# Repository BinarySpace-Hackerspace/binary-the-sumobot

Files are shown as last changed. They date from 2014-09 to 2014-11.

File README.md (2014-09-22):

Binary the SumoBot
==================

All related files for Binary the SumoBot

<b>Software</b>:

Various code available from some of the BinarySpace members

Sonar:

Library: http://playground.arduino.cc/Code/NewPing

<b>Hardware</b>:

If you just want to build one then want the following files:

sumo_v2.dxf - lasercut files
dozer_v2.stl - 3d printed bumper

If you want to modify then look at 

sumo.scad (openscad source)

Snippets used from the following scripts:

http://www.thingiverse.com/thing:9347
http://www.thingiverse.com/thing:18139

This was designed and built at BinarySpace (www.binaryspace.co.za)

Check out project page at http://www.binaryspace.co.za/?page_id=289

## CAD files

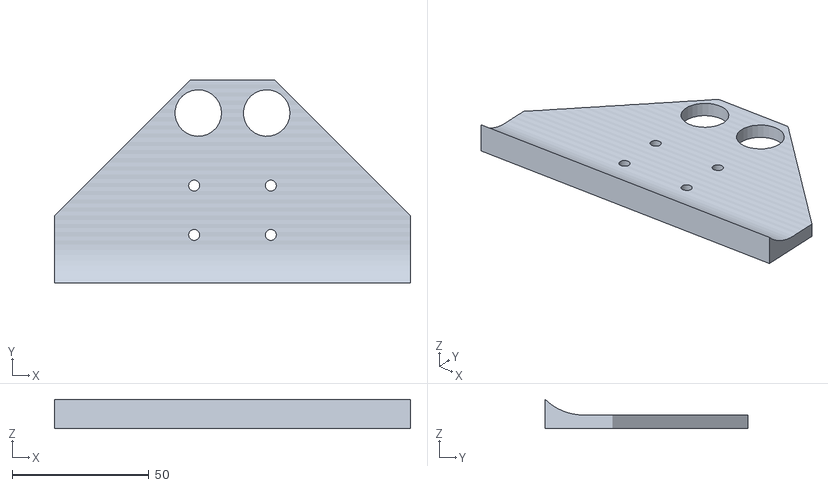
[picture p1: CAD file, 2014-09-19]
hardware/dozer_v2.stl
130.0 x 74.0 x 10.7

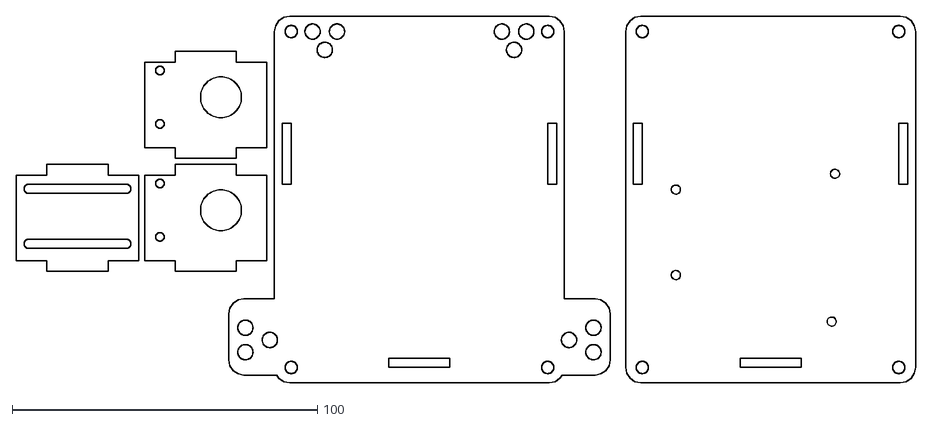
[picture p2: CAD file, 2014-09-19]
hardware/sumo_v2.dxf
294.5 x 120.0

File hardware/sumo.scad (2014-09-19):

// from http://www.thingiverse.com/thing:18139
include<arduino.scad>



projection( cut = true )
{


// dozerMount
translate( [-42, 0, 0] ) dozerMount();
// motorMount
translate( [0, 0, 0] ) motorMount();
translate( [0, 37, 0] ) motorMount();
// bottom base
translate( [90, 0, 0] ) bottomBase();

// top base - export as dxf for lasercut
translate( [205, 0, 0] ) topBase();
}



/*
// dozer - export as stl for 3d printing
dozerComplete();
*/

module dozerComplete()
{
	sonarHoleSize = 17;
	difference()
	{
		dozer();
		translate( [-67, 35, -20] ) rotate( [0, 0, -45] ) cube( [60, 120, 60] , center = true);
		translate( [67, 35, -20] ) rotate( [0, 0, 45] ) cube( [60, 120, 60], center = true );

		translate( [-12.5, 32, -10] )
		{
			cylinder( r = sonarHoleSize/2, h = 10 );
			translate( [25, 0, 0] ) cylinder( r = sonarHoleSize/2, h = 10 );
		}
		translate( [-25, 44, -20] ) cube( [50, 10, 40] );
	}
}

module dozer()
{


	rotate( [ 270, 0, 0] )
	{
		difference()
		{
			translate( [0, 0, 10] )cube( [ 130, 22, 80], center = true );
			translate( [0, 12, 0] ) cube( [ 130, 10, 120], center = true );


			for ( i = [0 : 20] )
			translate( [ -2, -18, -16 + (3 * i )] ) 
			{
				rotate( [ 0, 90, 0] ) cylinder( r = 20, h = 136, center = true, $fn = 64 );
			}

			translate( [-20, 15, -12] )
			{
				rotate( [0, 0, 90] )
				{
					translate( [0, 0, 23] ) 
					rotate( [90, 180, 90] )
					{

						translate( [0, 3, -30] )
						{
							translate( [6, 2.5, -2] ) cylinder( r = 2, h = 50, $fn = 64 );
							translate( [6, 2.5 + 18, -2] ) cylinder( r = 2, h = 50, $fn = 64 );
							translate( [34, 2.5, -2] ) cylinder( r = 2, h = 50, $fn = 64 );
							translate( [34, 2.5 + 18, -2] ) cylinder( r = 2, h = 50, $fn = 64 );
						}
					}
				}
			}
		}

	}
}


// from http://www.thingiverse.com/thing:9347
module roundedRect(size, radius)
{
	x = size[0];
	y = size[1];
	z = size[2];

	linear_extrude(height=z)
	
	hull()
	{
		// place 4 circles in the corners, with the given radius
		translate([(-x/2)+(radius/2), (-y/2)+(radius/2), 0])
		circle(r=radius);

		translate([(x/2)-(radius/2), (-y/2)+(radius/2), 0])
		circle(r=radius);

		translate([(-x/2)+(radius/2), (y/2)-(radius/2), 0])
		circle(r=radius);

		translate([(x/2)-(radius/2), (y/2)-(radius/2), 0])
		circle(r=radius);
	}
}


module bottomBase()
{
	difference()
	{
	union()
	{
		translate( [0, 15,0]) roundedRect( [90, 115, 3], 5 );

		// line follow sensors
		translate( [0, -30,0]) roundedRect( [120, 20, 3], 5 );
	}

	// spacer holes
	translate( [ 42, 70, -4] ) spacer();
	translate( [ -42, 70, -4] ) spacer();
	translate( [ 42, -40, -4] ) spacer();
	translate( [ -42, -40, -4] ) spacer();

	mounts();

	//line follow sensors mount
	translate( [-57, -27, -4] ) 
	{
		cylinder( r = 2.5, h = 10, $fn = 64 );
		translate( [0, -8, 0] ) cylinder( r = 2.5, h = 10, $fn = 64 );
		translate( [8, -4, 0] ) cylinder( r = 2.5, h = 10, $fn = 64 );
	}

	translate( [57, -27, -4] ) 
	{
		cylinder( r = 2.5, h = 10, $fn = 64 );
		translate( [0, -8, 0] ) cylinder( r = 2.5, h = 10, $fn = 64 );
		translate( [-8, -4, 0] ) cylinder( r = 2.5, h = 10, $fn = 64 );
	}

	translate( [35, 70, -4] ) 
	{
		cylinder( r = 2.5, h = 10, $fn = 64 );
		translate( [-8, 0, 0] ) cylinder( r = 2.5, h = 10, $fn = 64 );
		translate( [-4, -6, 0] ) cylinder( r = 2.5, h = 10, $fn = 64 );
	}

	translate( [-27, 70, -4] ) 
	{
		cylinder( r = 2.5, h = 10, $fn = 64 );
		translate( [-8, 0, 0] ) cylinder( r = 2.5, h = 10, $fn = 64 );
		translate( [-4, -6, 0] ) cylinder( r = 2.5, h = 10, $fn = 64 );
	}

	}
}


module topBase()
{
	difference()
	{
		translate( [0, 15,0]) roundedRect( [90, 115, 3], 5 );

		// spacer holes
		translate( [ 42, 70, -4] ) spacer();
		translate( [ -42, 70, -4] ) spacer();
		translate( [ 42, -40, -4] ) spacer();
		translate( [ -42, -40, -4] ) spacer();

		mounts();

//		translate( [-40, 34, 0] ) cube( [80, 30, 50] );
		translate([20,-25, 8]) rotate( [0, 0, 180] ) Arduino(1, 1, 1);

	}
}

module mounts()
{
	translate( [-45, 50, 3.1] ) 
	{
		translate( [0, 0, 23] ) 
		rotate( [90, 180, 90] )
		motorMount();
	}

	translate( [42, 50, 3.1] )
	{ 
		translate( [0, 0, 23] ) 
		rotate( [90, 180, 90] )
		motorMount();
	}

	translate( [-20, -40, 3.1] )
	{
		rotate( [0, 0, 90] ) 
		{
			translate( [0, 0, 23] ) 
			rotate( [90, 180, 90] )
			dozerMount();
		}
	}
}

module spacer()
{
	cylinder( r = 2, h = 25, $fn = 64 );
}

module dozerMount()
{
	difference()
	{
		union()
		{
			translate( [0, -5, 0] ) cube( [ 40, 28, 3] );
			translate( [ 10, -8.5, 0]) cube( [ 20, 35, 3] );
		}

		translate( [0, -2, 0] )
		{
			translate( [4, 2.5, -2] ) cylinder( r = 1.5, h = 10, $fn = 64 );
			translate( [4, 2.5 + 18, -2] ) cylinder( r = 1.5, h = 10, $fn = 64 );
			translate( [36, 2.5, -2] ) cylinder( r = 1.5, h = 10, $fn = 64 );
			translate( [36, 2.5 + 18, -2] ) cylinder( r = 1.5, h = 10, $fn = 64 );
		}

		translate( [4, -1, -3] ) cube( [32, 3, 10] );
		translate( [4, 17, -3] ) cube( [32, 3, 10] );

	}
}

module motorMount()
{
	difference()
	{
		union()
		{
			translate( [0, -5, 0] ) cube( [ 40, 28, 3] );
			translate( [ 10, -8.5, 0]) cube( [ 20, 35, 3] );
		}

		translate( [5, 2.75, -2] ) cylinder( r = 1.4, h = 10, $fn = 64 );
		translate( [5, 2.25 + 18, -2] ) cylinder( r = 1.4, h = 10, $fn = 64 );
		translate( [ 25, 11.5, -3] ) cylinder( r = 6.7, h = 10, $fn = 64 );
	}
}

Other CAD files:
hardware/arduino.scad

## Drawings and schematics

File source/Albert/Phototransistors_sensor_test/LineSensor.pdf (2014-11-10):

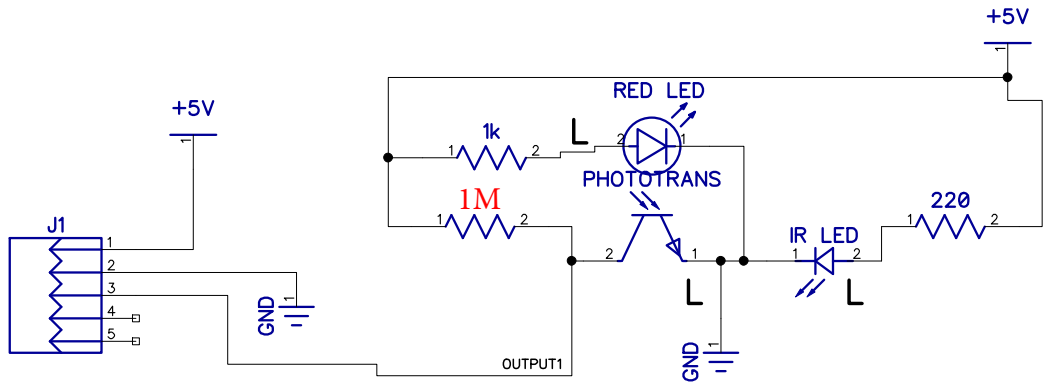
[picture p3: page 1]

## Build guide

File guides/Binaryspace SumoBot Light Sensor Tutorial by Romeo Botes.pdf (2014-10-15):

# Binaryspace SumoBot Light Sensor Tutorial

### By Romeo Botes (romeo.botes@gmail.com)

This tutorial shows how to build a simple IR Light Sensor for your SumoBot. You will need to build 4 sensors like these, two exactly the same and two others with a different pin layout for the other side of the SumoBot.

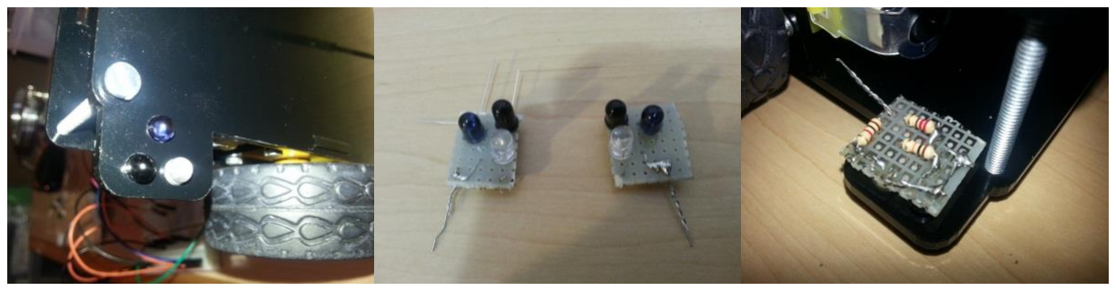
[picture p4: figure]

### Content:

1. Components
2. Placing
3. Soldering and Connecting
4. Cutting and Cleaning
5. Hook-up Wiring
6. Programming
7. Testing

### Components

- 1x 7pin by 5 pin cut Vero board (VB)
- 1x IR Transmitter (Tx)
- 1x IR Receiver (Rx)
- 1x LED (Any colour)
- 1x 10k Resistor
- 1x 1K Resistor
- 1x 220 Resistors
- 3x 0.2mm wire (red, black and any colour for signal in this example we used Yellow for signal)

PIN 1

PIN 7

PIN 8

### Placing

Place the components in the following matter on the VB (see Images).

- IR Tx
- Long Leg > Pin 7
- Short Leg > Pin 6
- IR Rx
- Long Leg > Pin 26
- Short Leg > Pin 27
- LED
- Long Leg > Pin 3
- Short Leg > Pin 4
- 1K Resistor
- Pin 1, 22
- 10K Resistor
- Pin 17, 20
- 220 Resistor
- Pin 30 ,33

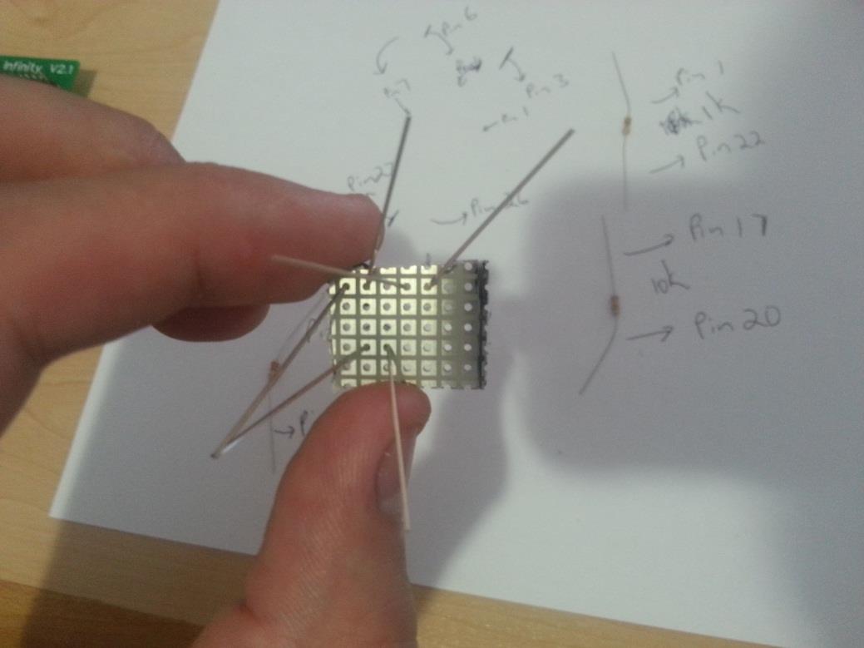
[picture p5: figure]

### Soldering and Connecting

Connect and solder the components in the following matter on the VB (see Images).

- Solder together Pin 4, 7, 27 this will be GND.
- Solder together Pin 17, 22, 30 this will be V5+.
- Connect and solder:
- Pin 1 to Pin 3
- Pin 6 to Pin 20
- Pin 26 to Pin 33

You can pull on of the Pins 17, 22, 30 through Pin-hole 29 and solder the other two at the back.

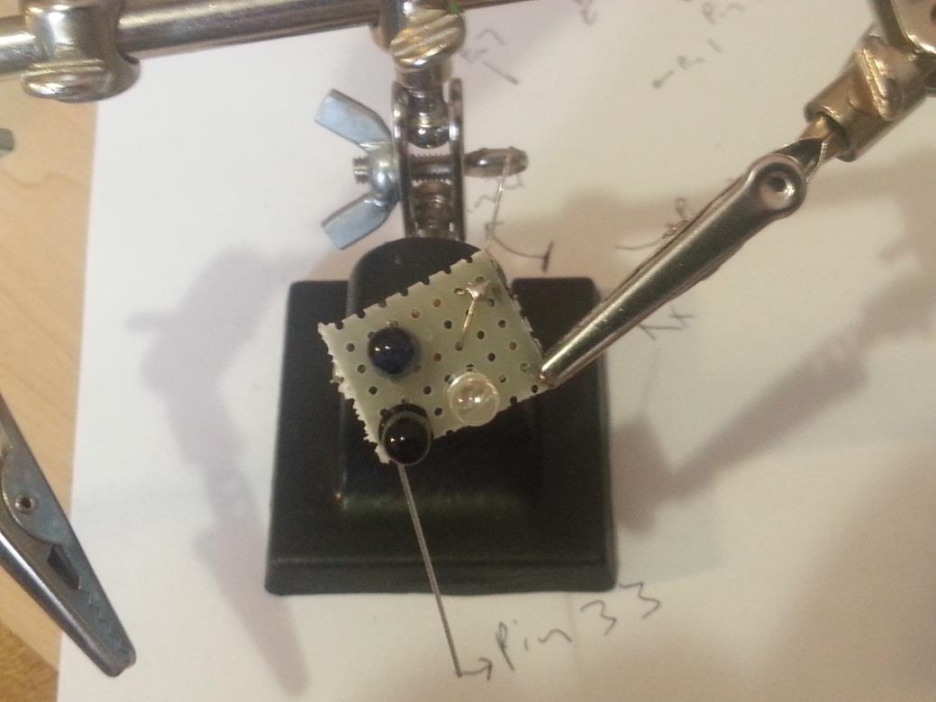
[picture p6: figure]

### Cutting and Cleaning

Cut away all excess wire leaving:

- The pulled thru wire on pin 29.
- One of the Pin 4, 7, 27 wires.

### Hook-up Wiring

Use your three 0.2mm wire (Red, Black, and Yellow) and connect them as follows:

- Connect Red wire to wire on Pin 29 and connect it to Arduino V5+.
- Connect Black wire to one of the Pin 4, 7, 27 wires and connect it to GND.
- Connect Yellow wire on the wire running between Pin 6 and Pin 20 and connect it to Arduino A0 or whichever one (A1-A5) you want to use for the sensor.

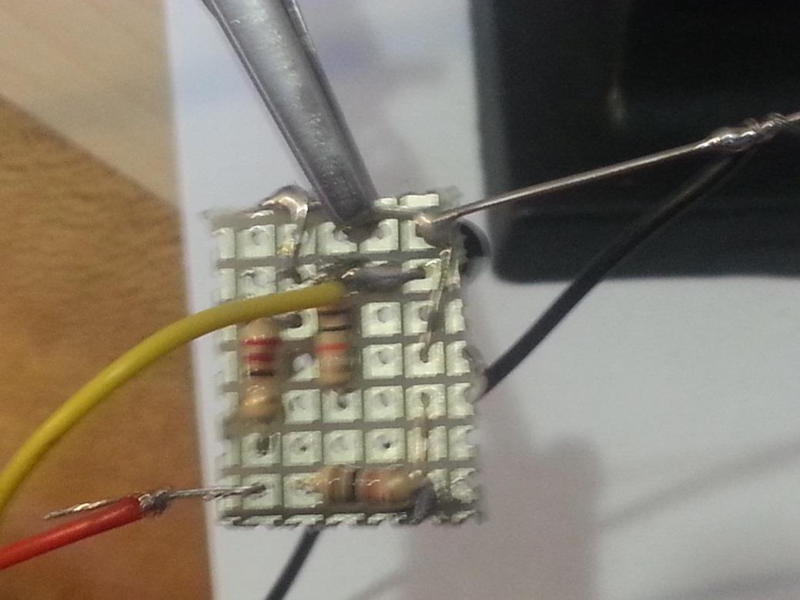
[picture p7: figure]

### Programming

Use the following code to test the sensor:

//////////////////////////////////////////////////////////////////////
int sensorPin = A0; // select the input pin for the potentiometer
int sensorValue = 0; // variable to store the value coming from the sensor

void setup() {
Serial.begin(9600);
}
void loop() {
// read the value from the sensor: sensorValue = analogRead(sensorPin); Serial.println(sensorValue);
delay(10);
}
//////////////////////////////////////////////////////////////////////

### Testing

When testing the sensor use a black and white piece of plastic, paper, etc.

DEFUALT AND BLACK MATTER

By default (point to nothing) and BLACK surfaces will present you with a high analogue value for the sensor of above 900, in our case it was about 995-996.

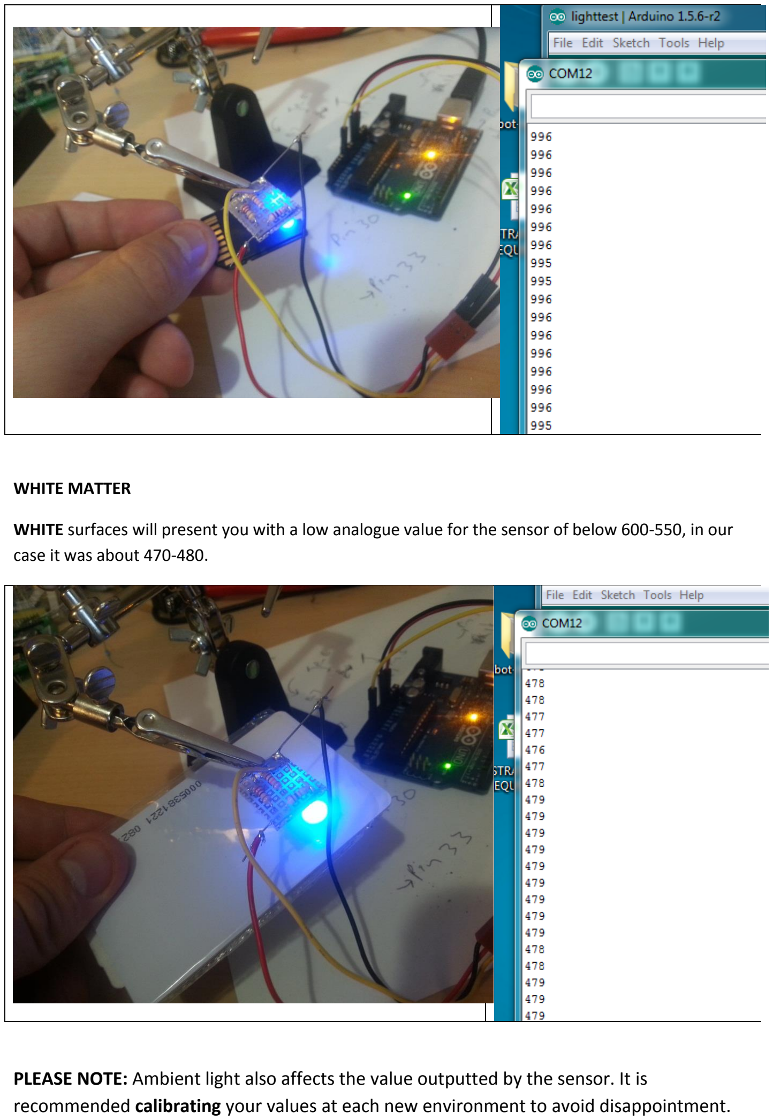
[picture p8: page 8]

WHITE MATTER

WHITE surfaces will present you with a low analogue value for the sensor of below 600-550, in our case it was about 470-480.

PLEASE NOTE: Ambient light also affects the value outputted by the sensor. It is recommended calibrating your values at each new environment to avoid disappointment.

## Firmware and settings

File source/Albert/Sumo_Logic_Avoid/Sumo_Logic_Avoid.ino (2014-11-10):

#define echoPin 4 // Echo Pin Input
#define trigPin 5 // Trigger Pin Output

#define motor1pole1 2 
#define motor1pole2 3
#define motor2pole1 7
#define motor2pole2 8

// map L293d motor enable pins to Arduino pins
#define enablePin1 9
#define enablePin2 10

#define M1_MAX_SPEED 100
#define M2_MAX_SPEED 100

#define motordelay 30
#define debugmotorsec 100

int mspeed = 160;  // pick a starting speed up to 255
int previousDistance;
int i;
int j;

void setup() {
  Serial.begin (115200);
  pinMode(trigPin, OUTPUT);
  pinMode(echoPin, INPUT);
  
  // set mapped L293D motor1 and motor 2 enable pins on Arduino to output (to turn on/off motor1 and motor2 via L293D)
  pinMode(enablePin1, OUTPUT);
  pinMode(enablePin2, OUTPUT);

  // set mapped motor poles to Arduino pins (via L293D)
  pinMode( motor1pole1 , OUTPUT);
  pinMode( motor1pole2, OUTPUT);
  pinMode( motor2pole1, OUTPUT);
  pinMode( motor2pole2 , OUTPUT);
  motorspeed(0, 0);
}

void loop() 
{
  echo();
  motorspeed(mspeed, mspeed);
}

void echo()
{
  //int maximumRange = 60; // Maximum range needed
  int minimumRange = 30; // Minimum range needed
  long duration, distance; // Duration used to calculate distance
  
  digitalWrite(trigPin, LOW);
  delayMicroseconds(2);
  digitalWrite(trigPin, HIGH);
  delayMicroseconds(10);
  digitalWrite(trigPin, LOW);
  
  duration = pulseIn(echoPin, HIGH);
  distance = (duration) / 58.2;
  Serial.print ("Distance\t");
  Serial.println (distance);
  
    if (distance <= minimumRange)
    {
      if (previousDistance > distance)
      {     
        i = random (1, 3);
        Serial.println (i);
        if (i == 1)
        {
          j = 2;
        }
        if (i == 2)
        {
          j = 1;
        }
      }
      motorforward(i);
      motorback(j);
      delay(debugmotorsec);
    }
      else
      {
        motorforward(1);
        motorforward(2);
        delay(debugmotorsec);
      }
    //delay(50);
    previousDistance = distance;
}

// MOTOR FUNCTIONS

void motorstop(int motornum){
  delay(motordelay);
  if (motornum == 1) {
    digitalWrite(motor1pole1, LOW);
    digitalWrite(motor1pole2, LOW);
  }
  else if (motornum == 2) {

    digitalWrite(motor2pole1, LOW);
    digitalWrite(motor2pole2, LOW);
  }
  delay(motordelay);
}

void motorforward(int motornum){
  if (motornum == 1) {
    digitalWrite(motor1pole1, HIGH);
    digitalWrite(motor1pole2, LOW);
  }
  else if (motornum == 2) {

    digitalWrite(motor2pole1, LOW);
    digitalWrite(motor2pole2, HIGH);
  }
  delay(motordelay);
}

void motorback(int motornum){
  if (motornum == 1) {
    digitalWrite(motor1pole1, LOW);
    digitalWrite(motor1pole2, HIGH);
  } 
  else if (motornum == 2) {
    digitalWrite(motor2pole1, HIGH);
    digitalWrite(motor2pole2, LOW);
  }
  delay(motordelay);
}

void motorspeed(int motor1speed, int motor2speed) {
  if (motor1speed > M1_MAX_SPEED ) motor1speed = M1_MAX_SPEED; // limit top speed
  if (motor2speed > M2_MAX_SPEED ) motor2speed = M2_MAX_SPEED; // limit top speed
  if (motor1speed < 0) motor1speed = 0; // keep motor above 0
  if (motor2speed < 0) motor2speed = 0; // keep motor speed above 0
  analogWrite(enablePin1, motor1speed);
  analogWrite(enablePin2, motor2speed);
}

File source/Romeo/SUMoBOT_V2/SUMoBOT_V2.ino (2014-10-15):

#include <NewPing.h>
// Use this code to test your motor with the Arduino board:

// if you need PWM, just use the PWM outputs on the Arduino
// and instead of digitalWrite, you should use the analogWrite command

// --------------------------------------------------------------------------- Motors
int Dist_Counter = 0;
int Dist_Average[] = {0, 0, 0, 0, 0, 0, 0, 0, 0, 0};
int Distance = 0;
int motor_left[] = {4, 3};
int motor_right[] = {5, 6};

int motor1enable = 10;
int motor2enable = 11;

int DistanceDetect = 15;

int enableLightOutput = 1;

int enableUSB = 0;
// --------------------------------------------------------------------------- Sonar
#define TRIGGER_PIN  13  // Arduino pin tied to trigger pin on the ultrasonic sensor.
#define ECHO_PIN     12  // Arduino pin tied to echo pin on the ultrasonic sensor.
#define MAX_DISTANCE 400 // Maximum distance we want to ping for (in centimeters). Maximum sensor distance is rated at 400-500cm.

NewPing sonar(TRIGGER_PIN, ECHO_PIN, MAX_DISTANCE); // NewPing setup of pins and maximum distance.

// --------------------------------------------------------------------------- Deff

const int buttonStart = 2;
bool Start = false;
int buttonState = 0;



int FL_SensorPin = A1;    // select the input pin for the potentiometer
int FL_SensorValue = 0;  // variable to store the value coming from the sensor
int FR_SensorPin = A0;    // select the input pin for the potentiometer
int FR_SensorValue = 0;  // variable to store the value coming from the sensor
int BL_SensorPin = A3;    // select the input pin for the potentiometer
int BL_SensorValue = 0;  // variable to store the value coming from the sensor
int BR_SensorPin = A2;    // select the input pin for the potentiometer
int BR_SensorValue = 0;  // variable to store the value coming from the sensor

int Value_Dark = 1000;
int Value_Light = 590;
//int Light_Freshold = 795;

int Light_Freshold_Front = 600;

int Light_Freshold_Back = 700;



// --------------------------------------------------------------------------- Setup
void setup() {
  Serial.begin(115200);

  // Setup motors
  int i;
  for (i = 0; i < 2; i++) {
    pinMode(motor_left[i], OUTPUT);
    pinMode(motor_right[i], OUTPUT);
  }
delay(5000);
}

// --------------------------------------------------------------------------- Loop
void loop() {


//  motortest();
  
  
  buttonState = digitalRead(buttonStart);









  // check if the pushbutton is pressed.
  // if it is, the buttonState is HIGH:
  if (buttonState == HIGH && Start == false) {
    Start = true;
  }

  //if (buttonState == HIGH && Start == true) {
  //  Start = false;
 // }

//  if (Start == true) { // IF START START
    FL_SensorValue = analogRead(FL_SensorPin);
    FR_SensorValue = analogRead(FR_SensorPin);
    BL_SensorValue = analogRead(BL_SensorPin);
    BR_SensorValue = analogRead(BR_SensorPin);

    if (enableLightOutput == 1) {
      Serial.print("FL:");
      Serial.println(FL_SensorValue);
      Serial.print("FR:");
      Serial.println(FR_SensorValue);
      Serial.print("BL:");
      Serial.println(BL_SensorValue);
      Serial.print("BR:");
      Serial.println(BR_SensorValue);
     
//delay(500);
   }
    Border_Check_Light();



 // } // IF START END

}

// --------------------------------------------------------------------------- Drive & Functions

void motortest()
{
  int i = 80;
 for (i = 80; i < 150; i++) {
   
     
  setMotor1Left(i, true);
  
  Serial.println(i);
   delay(2000);
   
 }

}


void setMotor1Left(int speed, boolean reverse)
{
  if (enableUSB == 1){
  speed = speed + 50;
  }
  analogWrite(motor1enable, speed + 420);
  digitalWrite(motor_left[0], ! reverse);
  digitalWrite(motor_left[1], reverse);
}

void setMotor2Right(int speed, boolean reverse)
{
    if (enableUSB == 1){
  speed = speed +50;
  }
  analogWrite(motor2enable, speed + 420);
  digitalWrite(motor_right[0], ! reverse);
  digitalWrite(motor_right[1], reverse);
}


void Detect() {

  delay(20);                      // Wait 50ms between pings (about 20 pings/sec). 29ms should be the shortest delay between pings.
  unsigned int uS = sonar.ping(); // Send ping, get ping time in microseconds (uS).

  int Dist = uS / US_ROUNDTRIP_CM;

Serial.print("Ping: ");
  Serial.print(Dist); // Convert ping time to distance and print result (0 = outside set distance range, no ping echo)
  Serial.println("cm");
  
  
  if (Dist_Counter < 9)
  {
    Dist_Average[Dist_Counter] = Dist;

  } else
  {
    Dist_Counter = -1;
  }

  Dist_Counter += 1;

  int sum = 0;

  for (int i = 0; i < 9; i++)
  {
    sum += Dist_Average[i];
  }

  Distance = sum / 9;

  


  if (Distance < DistanceDetect) {

    setMotor1Left(10, true);

    setMotor2Right(10, true);
    delay(15);
    //Serial.println("FWD");
  }
  else {
    setMotor1Left(-10, true);
    setMotor2Right(-10, false);
  }

}

void Border_Check_Light() {

  if (  FL_SensorValue <= Light_Freshold_Front)
  {

    setMotor1Left(2, false);
    setMotor2Right(1, false);
    delay(5);

  }

  else if (  FR_SensorValue <= Light_Freshold_Front)
  {
    setMotor1Left(1, false);
    setMotor2Right(2, false);
delay(5);
  }

  else if (  BL_SensorValue <= Light_Freshold_Back)
  {

    setMotor1Left(2, true);
    setMotor2Right(1, true);
    delay(5);
  }
  else if (  BR_SensorValue <= Light_Freshold_Back)
  {

    setMotor1Left(1, true);
    setMotor2Right(2, true);
    delay(5);
  }
  else if (  FL_SensorValue=Light_Freshold_Front && FR_SensorValue <= Light_Freshold_Front)
  {

    setMotor1Left(20, false);
    setMotor2Right(20, false);
    delay(5);
  }
  else if (  BL_SensorValue <= Light_Freshold_Back && BR_SensorValue <= Light_Freshold_Back)
  {

    setMotor1Left(20, true);
    setMotor2Right(20, true);
    delay(5);
  }




  else
  {

    Detect();


  }






}

void outputtoS(String text)
{
Serial.println(text);
}

//void Border_Check_Dark() {
//
//  if (  L1_SensorValue > Light_Freshold)
//  {
//
//
//  }
//
//  if (  L2_SensorValue > Light_Freshold)
//  {
//
//
//  }
//
//  if (  L3_SensorValue > Light_Freshold)
//  {
//
//
//  }
//  if (  L4_SensorValue > Light_Freshold)
//  {
//
//
//  }
//
//
//
//
//
//}


void motor_stop() {
  digitalWrite(motor_left[0], LOW);
  digitalWrite(motor_left[1], LOW);

  digitalWrite(motor_right[0], LOW);
  digitalWrite(motor_right[1], LOW);
  //delay(25);
}

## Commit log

2014-09-19 added hardware design
    [arduino.scad, dozer_v2.stl, sumo.scad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]
2014-09-21 added basic motor and sonar code
2014-10-15 added updated code from Romeo and his light sensor guide
2014-11-10 SumoBot Testing and Avoid Logic
    Echo sensor, motor config and phototransistor test code as well as
    logic to avoid obstacles
    [Echo_sensor_test.ino, Motor_config_test.ino, Phototransistors_sensor_test.ino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]
2014-11-10 Line Sensor Schematic
    Replaced 10k resistor with 1M in order for voltage to regulate over a
    wider range
